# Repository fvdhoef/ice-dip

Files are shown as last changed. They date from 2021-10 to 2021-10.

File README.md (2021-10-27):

# ICE-DIP

Designed by Frank van den Hoef in 2021.

This is a small FPGA board containing the Lattice iCE40 UltraPlus 5K FPGA. 

NOTE: At this moment this design is untested.

## Features
- Lattice ICE40UP5K-SG48I FPGA, 5K logic elements, 15KB+128KB embedded block RAM
- DIP40 form factor with machined pin headers for easy integration in retro computer designs.
- Level translating bus switches on all I/O pins to allow interfacing with 5V logic. (NOTE: output levels will still be max 3.3V)
- 2MB SPI flash for 1 to 4 configuration images.
- On-board crystal oscillator.
- On-board power supplies for 3.3V and 1.2V.
- Open-source hardware. [Schematic](pcb/ice-dip-schematic.pdf) and layout (in KiCad format) are free for you to use and modify.

## Renders
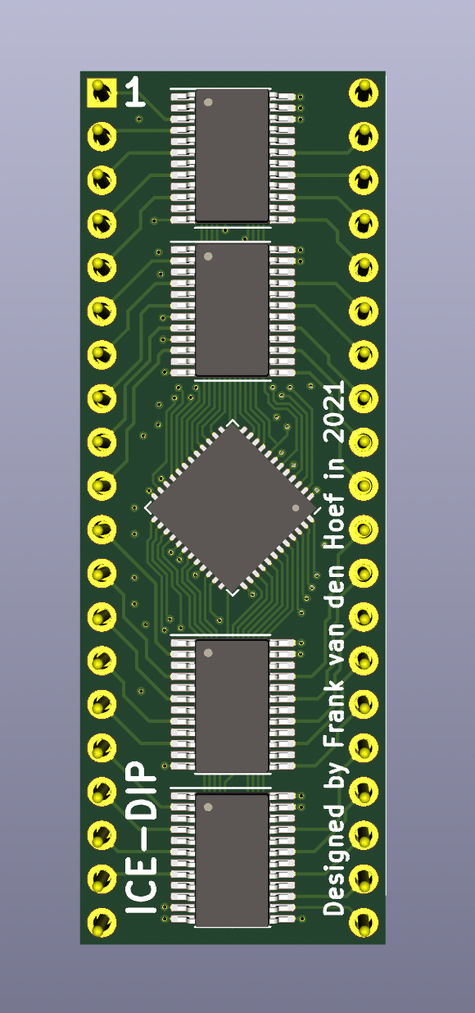
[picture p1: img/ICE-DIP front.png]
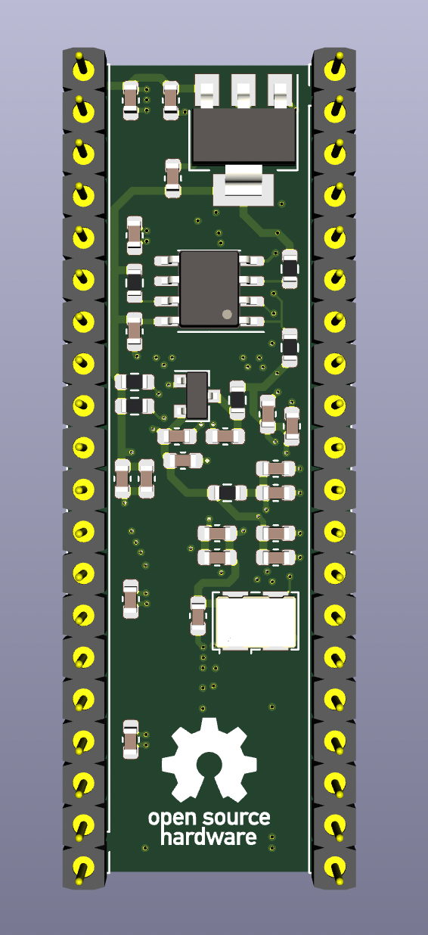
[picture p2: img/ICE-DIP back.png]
 

## Downloads
- [Schematic](pcb/ice-dip-schematic.pdf)
- [Bill of Materials](pcb/ice-dip-bom.csv)
- [Gerbers files](pcb/ice-dip-gerbers.zip)

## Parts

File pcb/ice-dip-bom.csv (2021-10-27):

Quantity | Value | Footprint | Refs
13 | 100nF | C0603 X5R/X7R | C1, C2, C3, C4, C6, C7, C8, C11, C13, C14, C15, C16, C17
8 | 4.7uF | C0603 X5R/X7R | C5, C9, C10, C12, C20, C21, C27, C28
1 | 1 | R0603 | R42
1 | 100 | R0603 | R5
5 | 10k | R0603 | R1, R2, R3, R4, R6
1 | SG-5032CAN | Oscillator 5.0x3.2mm | X1
1 | ICE40UP5K-SG48ITR50 | QFN-48-1EP_7x7mm_P0.5mm_EP5.3x5.3mm | U1
1 | W25Q16JVSNIQ | SOIC-8_3.9x4.9mm_P1.27mm | U2
4 | SN74CBTD3861PWR | TSSOP-24_4.4x7.8mm_P0.65mm | U5, U6, U7, U8
1 | LDL1117S33R | SOT-223-3_TabPin2 | U3
1 | MCP1700T-1202E/TT | SOT-23 | U4
2 | Pin1-20, Pin21-40 | Samtec TS-120-T-A | J1, J2

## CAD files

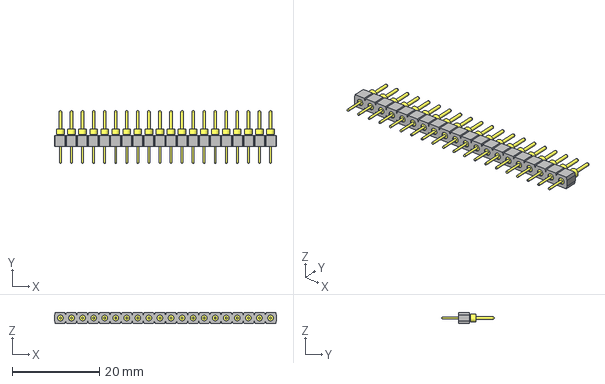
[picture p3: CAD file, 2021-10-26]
pcb/TS-120-T-A.stp
51.0 x 12.1 x 2.54 mm
_TS-120-G-A_socket
_-101-G-A_pins x 20

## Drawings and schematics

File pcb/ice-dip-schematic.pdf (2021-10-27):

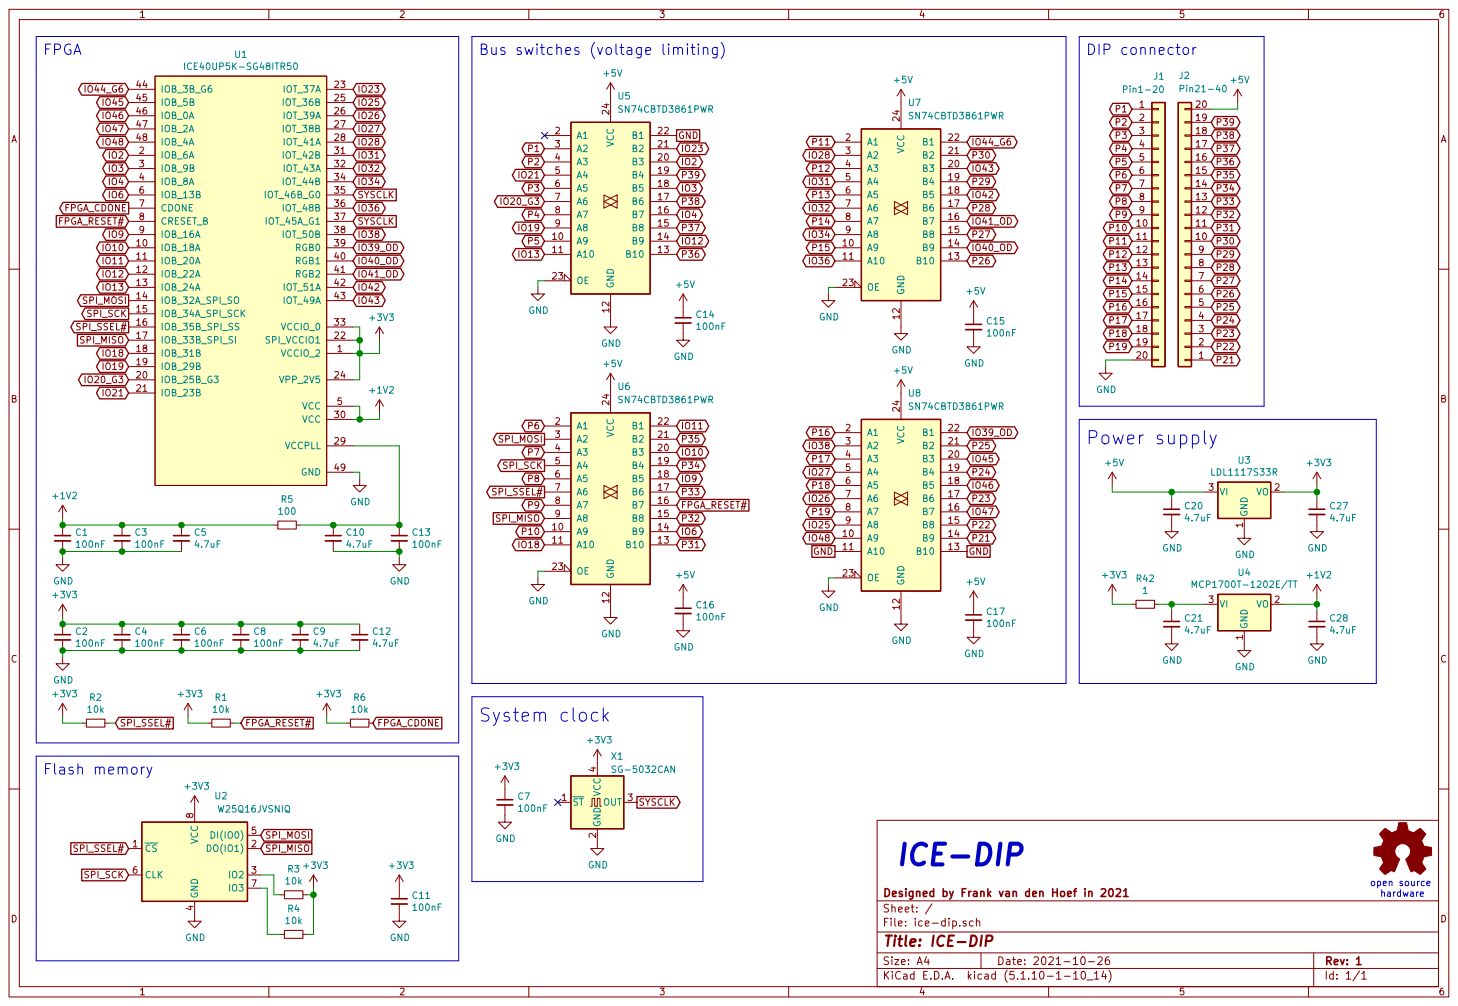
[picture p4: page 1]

Id: 1/1 Title: ICE-DIP

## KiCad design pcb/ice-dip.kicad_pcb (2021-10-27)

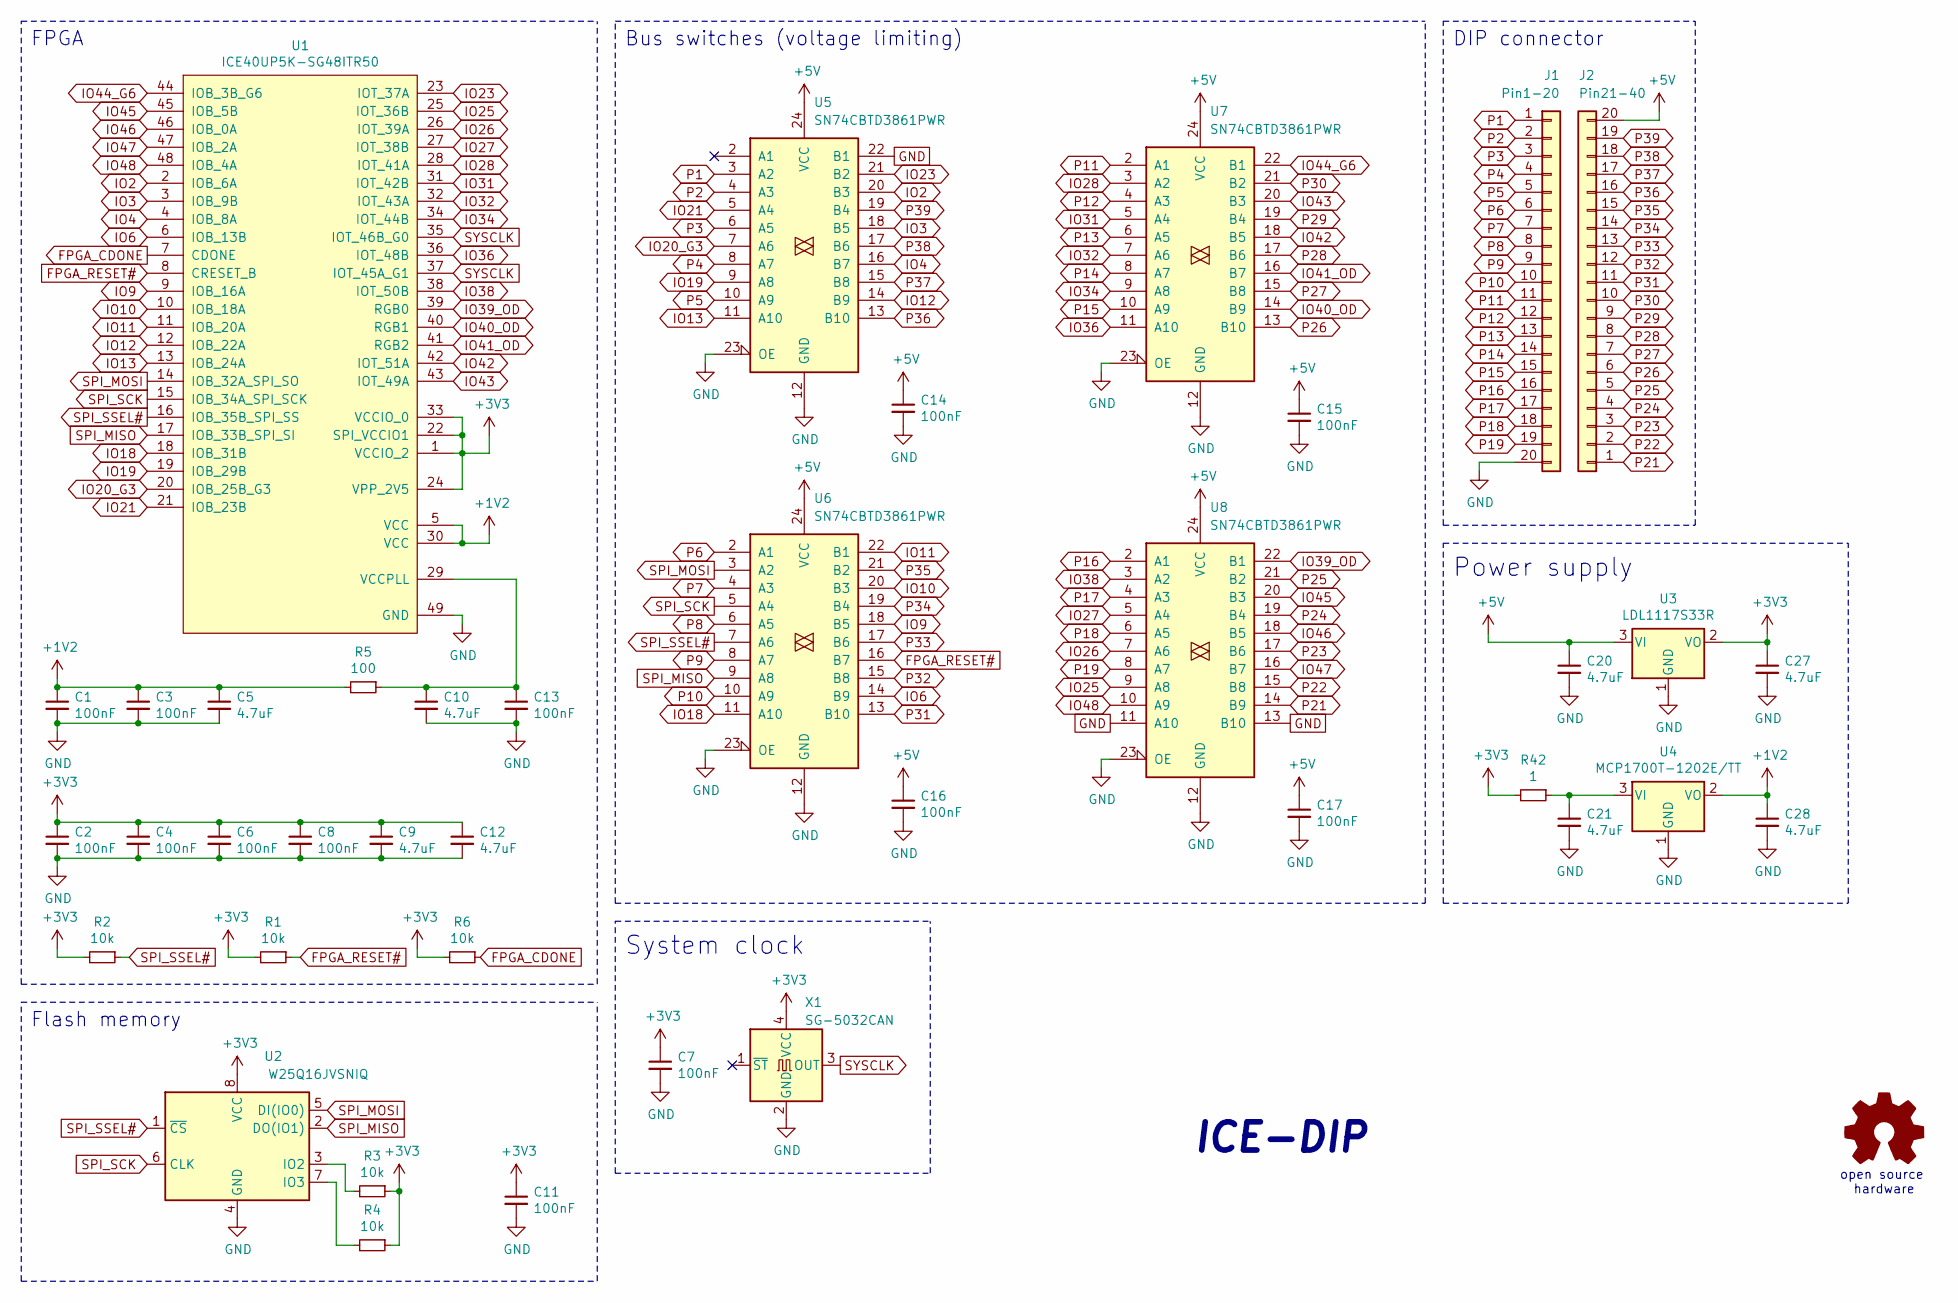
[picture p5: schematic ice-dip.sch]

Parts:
C1, C2, C3, C4, C6, C7, C8, C11, C13, C14, C15, C16, C17: 100nF; C_0603_1608Metric
C5, C9, C10, C12, C20, C21, C27, C28: 4.7uF; C_0603_1608Metric
J1: Pin1-20; PinHeader_1x20_P2.54mm_Vertical
J2: Pin21-40; PinHeader_1x20_P2.54mm_Vertical
LOGO1: Logo_Open_Hardware_Small; OSHW-Logo_7.5x8mm_SilkScreen
R1, R2, R3, R4, R6: 10k; R_0603_1608Metric
R5: 100; R_0603_1608Metric
R42: 1; R_0603_1608Metric
U1: ICE40UP5K-SG48ITR50; QFN-48-1EP_7x7mm_P0.5mm_EP5.3x5.3mm
U2: W25Q16JVSNIQ; SOIC-8_3.9x4.9mm_P1.27mm
U3: LDL1117S33R; SOT-223-3_TabPin2
U4: MCP1700T-1202E/TT; SOT-23
U5, U6, U7, U8: SN74CBTD3861PWR; TSSOP-24_4.4x7.8mm_P0.65mm
X1: SG-5032CAN; Oscillator_SMD_SeikoEpson_SG8002LB-4Pin_5.0x3.2mm

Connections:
+1V2: C1.1, C3.1, C5.1, C28.1, R5.2, U1.5 (VCC), U1.30 (VCC), U4.2 (VO)
+3V3: C2.1, C4.1, C6.1, C7.1, C8.1, C9.1, C11.1, C12.1, C27.1, R1.2, R2.2, R3.1, R4.1, R6.2, R42.2, U1.1 (VCCIO_2), U1.22 (SPI_VCCIO1), U1.24 (VPP_2V5), U1.33 (VCCIO_0), U2.8 (VCC), U3.2 (VO), X1.4 (VCC)
+5V: C14.1, C15.1, C16.1, C17.1, C20.1, J2.20, U3.3 (VI), U5.24 (VCC), U6.24 (VCC), U7.24 (VCC), U8.24 (VCC)
FPGA_CDONE: R6.1, U1.7 (CDONE)
FPGA_RESET#: R1.1, U1.8 (CRESET_B), U6.16 (B7)
GND: C1.2, C2.2, C3.2, C4.2, C5.2, C6.2, C7.2, C8.2, C9.2, C10.2, C11.2, C12.2, C13.2, C14.2, C15.2, C16.2, C17.2, C20.2, C21.2, C27.2, C28.2, J1.20, U1.49 (GND), U2.4 (GND), U3.1 (GND), U4.1 (GND), U5.12 (GND), U5.22 (B1), U5.23 (OE), U6.12 (GND), U6.23 (OE), U7.12 (GND), U7.23 (OE), U8.11 (A10), U8.12 (GND), U8.13 (B10), U8.23 (OE), X1.2 (GND)
IO2: U1.2 (IOB_6A), U5.20 (B3)
IO3: U1.3 (IOB_9B), U5.18 (B5)
IO4: U1.4 (IOB_8A), U5.16 (B7)
IO6: U1.6 (IOB_13B), U6.14 (B9)
IO9: U1.9 (IOB_16A), U6.18 (B5)
IO10: U1.10 (IOB_18A), U6.20 (B3)
IO11: U1.11 (IOB_20A), U6.22 (B1)
IO12: U1.12 (IOB_22A), U5.14 (B9)
IO13: U1.13 (IOB_24A), U5.11 (A10)
IO18: U1.18 (IOB_31B), U6.11 (A10)
IO19: U1.19 (IOB_29B), U5.9 (A8)
IO20_G3: U1.20 (IOB_25B_G3), U5.7 (A6)
IO21: U1.21 (IOB_23B), U5.5 (A4)
IO23: U1.23 (IOT_37A), U5.21 (B2)
IO25: U1.25 (IOT_36B), U8.9 (A8)
IO26: U1.26 (IOT_39A), U8.7 (A6)
IO27: U1.27 (IOT_38B), U8.5 (A4)
IO28: U1.28 (IOT_41A), U7.3 (A2)
IO31: U1.31 (IOT_42B), U7.5 (A4)
IO32: U1.32 (IOT_43A), U7.7 (A6)
IO34: U1.34 (IOT_44B), U7.9 (A8)
IO36: U1.36 (IOT_48B), U7.11 (A10)
IO38: U1.38 (IOT_50B), U8.3 (A2)
IO39_OD: U1.39 (RGB0), U8.22 (B1)
IO40_OD: U1.40 (RGB1), U7.14 (B9)
IO41_OD: U1.41 (RGB2), U7.16 (B7)
IO42: U1.42 (IOT_51A), U7.18 (B5)
IO43: U1.43 (IOT_49A), U7.20 (B3)
IO44_G6: U1.44 (IOB_3B_G6), U7.22 (B1)
IO45: U1.45 (IOB_5B), U8.20 (B3)
IO46: U1.46 (IOB_0A), U8.18 (B5)
IO47: U1.47 (IOB_2A), U8.16 (B7)
IO48: U1.48 (IOB_4A), U8.10 (A9)
unnamed: C10.1, C13.1, R5.1, U1.29 (VCCPLL)
unnamed: C21.1, R42.1, U4.3 (VI)
unnamed: R3.2, U2.3 (IO2)
unnamed: R4.2, U2.7 (IO3)
P1: J1.1, U5.3 (A2)
P2: J1.2, U5.4 (A3)
P3: J1.3, U5.6 (A5)
P4: J1.4, U5.8 (A7)
P5: J1.5, U5.10 (A9)
P6: J1.6, U6.2 (A1)
P7: J1.7, U6.4 (A3)
P8: J1.8, U6.6 (A5)
P9: J1.9, U6.8 (A7)
P10: J1.10, U6.10 (A9)
P11: J1.11, U7.2 (A1)
P12: J1.12, U7.4 (A3)
P13: J1.13, U7.6 (A5)
P14: J1.14, U7.8 (A7)
P15: J1.15, U7.10 (A9)
P16: J1.16, U8.2 (A1)
P17: J1.17, U8.4 (A3)
P18: J1.18, U8.6 (A5)
P19: J1.19, U8.8 (A7)
P21: J2.1, U8.14 (B9)
P22: J2.2, U8.15 (B8)
P23: J2.3, U8.17 (B6)
P24: J2.4, U8.19 (B4)
P25: J2.5, U8.21 (B2)
P26: J2.6, U7.13 (B10)
P27: J2.7, U7.15 (B8)
P28: J2.8, U7.17 (B6)
P29: J2.9, U7.19 (B4)
P30: J2.10, U7.21 (B2)
P31: J2.11, U6.13 (B10)
P32: J2.12, U6.15 (B8)
P33: J2.13, U6.17 (B6)
P34: J2.14, U6.19 (B4)
P35: J2.15, U6.21 (B2)
P36: J2.16, U5.13 (B10)
P37: J2.17, U5.15 (B8)
P38: J2.18, U5.17 (B6)
P39: J2.19, U5.19 (B4)
SPI_MISO: U1.17 (IOB_33B_SPI_SI), U2.2 (DO(IO1)), U6.9 (A8)
SPI_MOSI: U1.14 (IOB_32A_SPI_SO), U2.5 (DI(IO0)), U6.3 (A2)
SPI_SCK: U1.15 (IOB_34A_SPI_SCK), U2.6 (CLK), U6.5 (A4)
SPI_SSEL#: R2.1, U1.16 (IOB_35B_SPI_SS), U2.1 (~CS), U6.7 (A6)
SYSCLK: U1.35 (IOT_46B_G0), U1.37 (IOT_45A_G1), X1.3 (OUT)

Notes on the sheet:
FPGA
Flash memory
Power supply
Bus switches (voltage limiting)
DIP connector
System clock
open source hardware
ICE-DIP

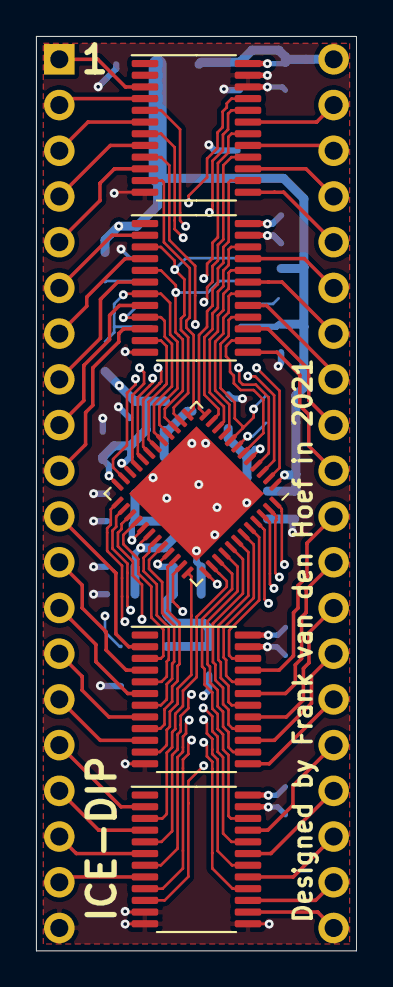
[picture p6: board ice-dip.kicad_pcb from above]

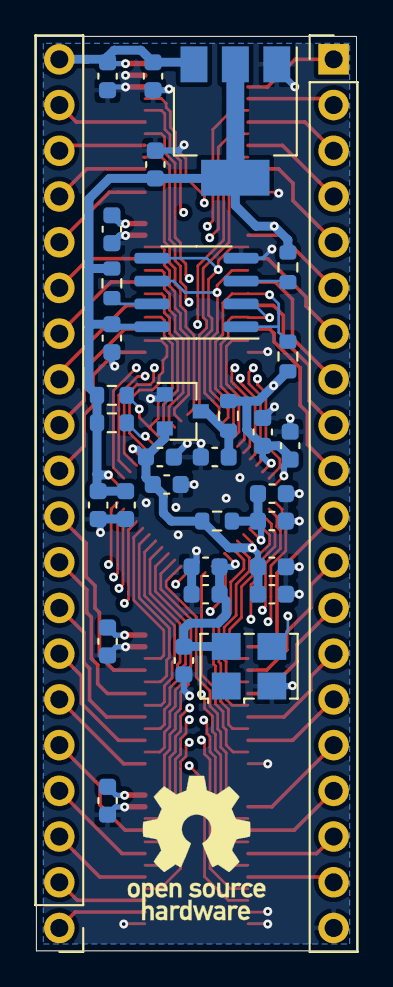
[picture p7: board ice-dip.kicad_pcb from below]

Board: 4 copper layers, 17.8 x 50.8 mm, 40 parts (35 on the bottom side), 86 nets.

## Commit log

2021-10-26 Initial commit.
    [TS-120-T-A.stp, ice-dip.kicad_pcb, ice-dip.sch]
2021-10-26 Added schematic in PDF format.
2021-10-27 Library for ICE-DIP component. Fixing some small issues.
    [ice-dip.kicad_pcb, ice-dip.sch]
2021-10-27 Updating schematic.
2021-10-27 Added extra copper pours. Added gerbers + bill of materials.
    [ice-dip-bom.csv, ice-dip.kicad_pcb]

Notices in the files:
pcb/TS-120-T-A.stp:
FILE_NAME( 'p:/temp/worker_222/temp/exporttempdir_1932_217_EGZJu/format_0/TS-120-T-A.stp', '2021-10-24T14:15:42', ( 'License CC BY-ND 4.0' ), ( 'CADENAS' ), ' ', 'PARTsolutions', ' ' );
